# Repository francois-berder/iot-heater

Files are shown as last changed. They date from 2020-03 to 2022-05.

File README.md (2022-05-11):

# Connected heater

The architecture of this solution is as follows: a base station is running and parses incoming SMS. Each heater controller connects to the base station regularly and requests the current heater state.

## Base station

The base station is responsible for parsing incoming SMS that contains commands. It then keeps track of the heater state (off, eco, defrost...) and responds to requests.
It is based on a Raspberry Pi connected to a SIM5320E for cellular connection.

### Hardware

See `docs/base_station_assembly_guide.md` on how to assemble the base station.

### Software

The software is a daemon running on Linux. It communicates with smstools to send/receive SMS from a 3G module.
See `base_station/README.md` for more information.

## Heater controller (or IOT-heater)

Each electric heater can be controlled by sending a SMS to the base station. Heater controllers periodically connect to the base station to retrieve the current heater state.

Electric heaters are controlled by one wire:

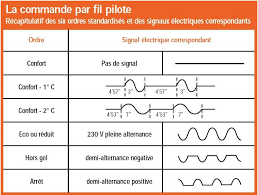
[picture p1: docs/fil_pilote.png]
heater control wire


See [here](https://www.planete-domotique.com/blog/2012/01/05/piloter-un-radiateur-grace-a-son-fil-pilote/) (in french) for more information on this control wire.

### Hardware

Heater controllers are built around a ESP8266 which controls two solid state relays. A small 220VAC to 5VDC module is used to power the ESP8266.
See Kicad files in folder `hardware` for more information.

See `docs/iot_heater_assembly_guide.md` for more information on how to assemble the heater controller.

### Firmware

The firmware is implemented using Arduino libraries for ESP8266.
See `heater_firmware/README.md` for more information.

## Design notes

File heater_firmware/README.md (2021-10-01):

# Heater firmware

This project aims at controlling an electric heater using an ESP8266 and a custom board. This board connects regularly to a base station to obtain the desired heater state (off, defrost, eco...) and controls the heater via a one-wire connection.

## Requirements

[arduino-cli](https://github.com/arduino/arduino-cli) is used to compile and upload binary to the ESP8266 if you are using the Makefile. If you are using the Arduino IDE, you can skip this step.

Run the following command to install arduino-cli:

```sh
curl -fsSL https://raw.githubusercontent.com/arduino/arduino-cli/master/install.sh | BINDIR=/usr/local/bin sh
```

Install ESP8266 board in Arduino IDE:
  1. Open File -> Preferences (or Arduino -> Preferences on MacOS)
  2. Enter `http://arduino.esp8266.com/stable/package_esp8266com_index.json` in the Additional Boards Manager URLs field
  3. Go to Tools -> Board -> Boards Manager and install ESP8266 by ESP8266 Community (version >= 3.0.2)

Arduino library dependencies:

- [ESP8266mDNS](https://github.com/esp8266/Arduino/tree/master/libraries/ESP8266mDNS)
- [ESPAsyncTCP](https://github.com/me-no-dev/ESPAsyncTCP)
- [ESPAsyncWebServer](https://github.com/me-no-dev/ESPAsyncWebServer)
- [ESP8266TrueRandom](https://github.com/marvinroger/ESP8266TrueRandom)
- [NTPClient](https://github.com/arduino-libraries/NTPClient)
- [Uptime-Library](https://github.com/YiannisBourkelis/Uptime-Library)

## Build & Flash instructions

You can either use the Arduino IDE to compile and flash the board, or use the Makefile (requires `arduino-cli`) and run these commands:

```sh
make
make upload
```

## Serial port

The firmware opens a serial connection (115200 8N1) over USB which is currently used only for debug. Run this command to compile/upload and get serial output from the board:

```sh
make term
```

## LED

| Status | LED |
| --- | --- |
| Not commissioned | LED ON |
| Not commissioned but someone on WiFi | LED flash every 100ms |
| Not connected to WiFi | LED flash every 500ms |
| Not connected to base station | LED flash every 3 seconds |
| All OK | LED ON only if reset button is pressed |

## Reset button

If the device is in commissioned mode, pressing the reset button for 10 seconds will reset
the device and clear its configuration. The device comes up in uncommissioned mode.

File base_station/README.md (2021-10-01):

# Base station

## Software

### Build instructions

The program depends on [libmicrohttpd](https://www.gnu.org/software/libmicrohttpd/).
On Ubuntu, run `sudo apt install libmicrohttpd-dev` to install it.

Type `make` or `BUILDTYPE=debug make` to build `base_station` program.

### Raspberry Pi setup

Do not plug anything to the Raspberry Pi apart from the microUSB to power the device. Follow these steps:

1. Flash latest Raspbian on a microSD card
2. Create an empty file named `ssh` in `/boot`
3. Add `wpa_supplicant.conf` in /boot with the following content:

```
country=FR
ctrl_interface=DIR=/var/run/wpa_supplicant GROUP=netdev
update_config=1

network={
  ssid="NETWORK-NAME"
  psk="NETWORK-PASSWORD"
}
```

4. Disable bluetooth by adding `dtoverlay=disable-bt` in `/boot/config.txt`
5. Build installer by running `base_station_installer/build.sh` and transfer this file to the microSD card in `/home/pi`
6. Boot Pi using micro sdcard
7. Login over SSH
8. Change password by running `passwd`
9. Run installer on Raspberry Pi
10. Shutdown Raspberry pi by running `sudo shutdown now`
11. Power up device

## SMS commands

| SMS | Description |
| --- | --- |
| HELP | Reply with basic commands |
| PING | Reply with `PONG` |
| VERSION | Reply with base station software version |
| ALL OFF | Set heater state to OFF |
| ALL DEFROST | Set heater state to DEFROST |
| ALL ECO | Set heater state to ECO |
| ALL COMFORT | Set heater state to COMFORT |
| ALL ON | Set heater state to COMFORT |
| HEATER <name> OFF | Set heater <name> state to OFF |
| HEATER <name> DEFROST | Set heater <name> state to DEFROST |
| HEATER <name> ECO | Set heater <name> state to ECO |
| HEATER <name> COMFORT | Set heater <name> state to COMFORT |
| HEATER <name> ON | Set heater <name> state to COMFORT |
| GET DEFAULT | Reply with current default heater state |
| GET HEATER <name> | Reply with current heater state |
| GET IP | Reply with public IP address |
| LOCK | Only phones whitelisted can send SMS |
| UNLOCK <pin> | All phones can send SMS (default PIN: 1234) |
| ADD PHONE <number> | Add phone number to whitelist |
| REMOVE PHONE <number> | Remove phone number from whitelist |
| DEBUG FILESTATE | Send content of `/var/lib/base_station.state` |
| DEBUG STATE | Send default state and all heater state |
| DEBUG REBOOT | Reboot Raspberry Pi |
| DEBUG WIFI | Get Wifi connection information |
| DEBUG LOG | Send `basestation.service` system logs |
| DEBUG UPTIME | Send Raspberry Pi uptime |
| SET EMERGENCY PHONE <number> | Set emergency phone number |
| REMOVE EMERGENCY PHONE | Remove emergency phone |

### Phone whitelist

By default, all text messages are parsed by the base station software and commands are executed regardless. This implies that anyone that knows the phone number of your base station can control your heating at home. To counter this threat, specific phones can be whitelisted and any text messages sent from a phone not belonging in the whitelist are discarded.

To use this feature,

1. Add your phone number to the whitelist: `ADD PHONE <your-phone-number>`
2. Send this command to enable this feature: `LOCK`

Any phone can send the `UNLOCK` command (useful if you whitelisted the wrong phone number !).

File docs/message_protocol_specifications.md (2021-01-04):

# Message protocol specifications

The base station communicates with heater controllers using a simple protocol.
The protocol consists of fixed size messages (64 bytes). Each message first starts by a header (16 bytes in size) leaving only 48 bytes for message-specific data. All unused bytes must be set to 0xFF.

## Message header

### Message header layout

| Parameter | Size (bytes) |
| --- | ---: |
| Protocol version | 1 |
| Type | 1 |
| MAC address | 6 |
| Counter | 8 |

For now, the protocol version is 1.

The counter is present to allow the base station to detect if a heater controller rebooted. It should be initialized randomly at boot and incremented whenever a message is sent.

### Message types

| Type | Value |
| --- | ---: |
| `REQ_HEATER_STATE` | 1 |
| `HEATER_STATE_REPLY` | 2 |

## `REQ_HEATER_STATE` message

This message may contain a NULL-terminated string that represents the name of the heater controller, making it possible for the base station to send a specific state to each heater.

## `HEATER_STATE_REPLY` message

This message contains only one parameter of size one byte that indicates the heater state. It can take the following values:

| Heater state | Value |
| --- | ----: |
| OFF | 0 |
| DEFROST | 1 |
| ECO | 2 |
| COMFORT/ON | 3 |

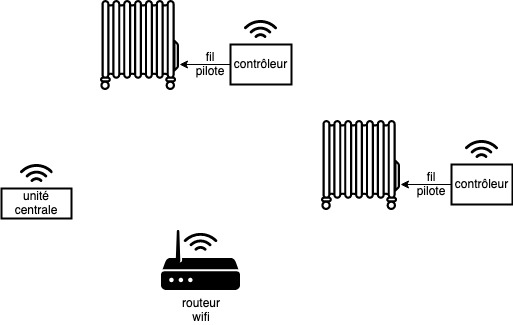
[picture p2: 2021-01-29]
docs/user_guide/connected_heater_overview.jpg

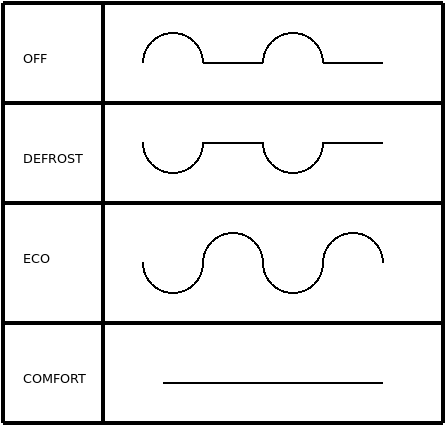
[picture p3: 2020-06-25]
docs/heater_control_wire.png

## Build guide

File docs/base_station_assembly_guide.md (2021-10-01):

# Assembly unit guide for base station

This document is a step by step guide on how to assemble and test base station
device.

## Components required

- Raspberry Pi Zero W
- SIM5320E module
- one micro SD card
- a micro USB to USB-A adapter
- a short micro USB cable
- one 2200uF capacitor (capacitance needs >= 1000uF)
- 2 small wires
- one ABS box

## Assembly

1. Follow the `Raspberry Pi setup` in `base_station/README.md` on how to setup the software on the Raspberry Pi
2. Solder the capacitor on pins 2 and 6 of the Raspberry Pi 40-pin header.
3. Solder one wire from pin 2 of the Raspberry Pi to 5V pin on the SIM5320E
4. Solder one wire from pin 6 of the Raspberry Pi to GND pin on the SIM5320E

The SIM5320E module requires a 4V power supply capable of handling 2A bursts. On the SIM5320E module, a diode lowers the input voltage from 5V to around 4V. Hence, both the Raspberry Pi and the SIM5320E must be powered with a 5V power supply. However, we cannot provide power to the 3G module from the USB connector of the Pi. That is why we need to solder two wires from the Raspberry Pi to the SIM5320E. The large capacitor is there to ensure that the SIM5320E and the Raspberry Pi will not brown when the SIM5320E draws lots of current.

5. Disable SIM card PIN (Can be done on any phone)
6. Insert SIM card in SIM5320E slot
7. Connect the raspberry Pi and SIM5230E with a micro-USB to micro-USB cable.

## Power on

1. Connect to the Raspberry Pi via ssh using public/private keys printed while building the installer.
2. Check that SIM5320E is connected by looking at the content of `/dev`. You should see several `/dev/USB<X>` entries.
3. Check that the basestation service is running: `sudo service basestation status`

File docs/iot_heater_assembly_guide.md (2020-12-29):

# Assembly unit guide for IOT-heater

This document is a step by step guide on how to assemble and test a IOT-heater
device.

## Step 1: Soldering components

Solder the following components on the PCB:

- D1 (5mm green LED)
- D3 (1N40005)
- D4 (1N40005)
- SW1 (push button)
- C1 (0.1uF)
- R1 (1k resistor)
- R2 (1k resistor)
- R4 (1k resistor)
- R7 (1k resistor)
- U2 (CPC1540)
- U3 (CPC1540)
- U1 (2x 15pin header)
- 220VAC to 5VDC converter

Pull-down/Pull-up resistors truth table:

| |  R5  |  R6  |  R8  |  R9  |
| --- | ---- | ---- | ---- | ---- |
| OFF |  fit | | |  fit |
| CONFORT | |  fit | |  fit |
| ECO |  fit | |  fit | |
| DEFROST | |  fit |  fit | |

## Step 2: Power converter test

Do **not** plug a ESP8266

1. Power unit from 220VAC
2. Check that LED from power converter is ON
3. With a multimeter, check power converter output is in range 4.8-5.2V

If successful, solder 5V & GND wires (red wire and black wire)

## Step 3: ESP8266 power test

Plug a ESP8266 device in the unit.

1. Plug a ESP8266
2. Power unit from 220VAC
3. Check LED on ESP8266 is solid ON

## Step 4: ESP8266 programming

1. Connect USB cable from PC to ESP8266
2. Download latest release on https://github.com/francois-berder/iot-heater
3. Run `arduino-cli upload -b esp8266:esp8266:nodemcuv2 -p <serial-port> -i <firmware-file>`

## Step 5: Uncommissioned mode test

1. Power unit from 220VAC
2. Check green LED is solid ON
3. Check WiFi network is present
4. Connect to WiFi network
5. Go to http://192.168.0.1/ and check if a webpage can be seen

## Step 6: commissioned mode test

1. Power unit from 220VAC
2. Go to http://192.168.0.1/ and enter WiFi credentials to commission device
3. Check green LED is off
4. Press for once second the reset button and check that green LED is on
5. Power down base station and check green LED flash every 3 seconds
6. Power down WiFi and check green LED flash every 500ms

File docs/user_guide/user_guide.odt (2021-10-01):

Chauffage connecté

guide d’utilisation

2021-10-01

Version 1

# Description

Le chauffage connecté fonctionne grâce à deux types d’éléments : une unité centrale et les contrôleurs de radiateur. Ces appareils communiquent entre eux grâce au réseau WiFi existant.


Figure 1: Vue d'ensemble de la solution de chauffage connecté

## Unité centrale

L’unité centrale communique avec un modem 3G, pour recevoir et envoyer des SMS, et répond aux requêtes des contrôleurs de radiateur. L’unité centrale est connecté au réseau WiFi de la maison. Il se compose de deux modules : un Raspberry Pi Zero W qui exécute le logiciel de chauffage connecté ainsi qu’un modem 3G relié par USB au Raspberry Pi.

L’unité centrale n’initie jamais une connexion à un contrôleur de radiateur. Il attend les requêtes des contrôleurs et y répond lorsqu’il en reçoit une. Cela a plusieurs conséquences importantes. Il n’est pas possible de connaître à tout moment l’état d’un radiateur. On ne peut que connaître l’état dans lequel le radiateur devrait se trouver. Cependant, cette architecture permet de diminuer la consommation d’énergie des contrôleurs car ils peuvent rester en veille entre deux requêtes.

## Contrôleur radiateur

Les radiateurs électriques sont contrôlés par un fil pilote qui prend la place du fil terre. Ainsi, le contrôleur de radiateur contrôle l’état d’un radiateur via le fil pilote[3].

Les fils phase et neutre alimentent le contrôleur et le radiateur. Un bouton reset est présent. On peut l’appuyer en insérant une pointe de stylo. Il permet de réinitialiser le contrôleur. Enfin, une LED verte est présente pour afficher le statut du contrôleur.

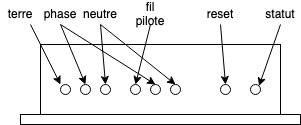
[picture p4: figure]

Figure 2: Vue de côté d'un contrôleur de radiateur

LED | Statut
LED allumée | Le contrôleur n’est pas initialisé
LED clignote toutes les 100 millisecondes | Le contrôleur n’est pas initialisé mais un appareil a rejoint le réseau WiFi du contrôleur
LED clignote toutes les 500 millisecondes | Le contrôleur est initialisé mais n’est pas connecté au WiFi de la maison
LED clignote toutes les 3 secondes | Le contrôleur est initialisé mais n’arrive pas à se connecter à l’unité centrale
LED on si le bouton reset est appuyé, sinon la LED reste éteinte | Le contrôleur est initialisé et fonctionne correctement.

# Installation

## Unité centrale

Avant de mettre en route l’unité centrale, il est vivement recommandé de configurer la box internet pour lui réserver une adresse IP.

Procédure d’installation de l’unité centrale :

1. Ouvrez le boîtier de l’unité centrale et insérez une carte SIM. Assurez-vous que la carte SIM est déverrouillée, c’est-à-dire qu’il n’y a pas besoin d’entrer un code PIN pour la faire fonctionner.
2. Assurez vous que le modem 3G est connecté au Raspberry Pi par un mini câble USB.
3. Connectez l’antenne 3G
4. Pour alimenter l’unité centrale, utilisez une alimentation 5V 2.5A. Il est recommandé d’utiliser une alimentation 5V 12W pour Raspberry Pi. Faîtes attention aux caractéristiques de votre alimentation car il n’existe aucune protection contre une tension trop élevée dans l’unité centrale.
5. Refermez le boîtier.

Lorsque l’appareil est sous tension, des LED vertes et rouge sont allumées (non visible si le boîtier est fermé).

Vous pouvez placer votre unité centrale où vous voulez tant que les connexions WiFi et 3G sont stables.

## Contrôleur radiateur

Avant d’initialiser un contrôleur, il est recommandé de configurer la box internet pour réserver une adresse IP à celui-ci.

Procédure d’installation d’un contrôleur :

1. Assurez vous que le radiateur est hors tension
2. Connectez les fils phase/neutre/terre au contrôleur
3. Connectez les fils phase/neutre/pilote au radiateur
4. Allumez le radiateur
5. Appuyez sur le bouton reset jusqu’à ce que la LED reste allumée
6. Connectez vous au réseau WiFi du contrôleur (le nom et mot de passe de ce réseau WiFi sont marqués sur le côté du boîtier)
7. Ouvrez un navigateur internet et allez à l’adresse http://www.heater.local ou http://192.168.1.1
8. Remplissez le formulaire et appuyez sur le bouton Register. Le réseau WiFi du contrôleur est supprimé et l’appareil tente de se connecter au réseau WiFi grâce aux informations fournis par le formulaire. Si cette connexion réussit, l’appareil est initialisé et se connecte régulièrement à l’unité centrale.

Le nom du radiateur doit être composé de lettres minuscule, majuscule ou de chiffres. Il ne doit pas y avoir d’espaces ou d’autres symboles dans le nom du radiateur.

Si vous initialisez plusieurs contrôleurs, évitez de leur donner le même nom. De plus, deux contrôleurs nommés Salon et SALON sont considérés comme ayant le même nom.

Attention ! Ne connectez pas plusieurs radiateurs à un seul contrôleur, les composants ne sont pas spécifié pour des courants trop élevé (maximum : 13A).

# Utilisation

Les radiateurs se pilotent uniquement par SMS via l'unité centrale. Il n'existe aucun autre moyen de changer l'état d'un radiateur.

Toutes les commandes dans ce document sont écrites en lettre majuscule, cependant l'unité centrale ne fait aucune différence si une lettre est en majuscule ou en minuscule, y compris pour les noms des radiateurs.

Les radiateurs sont toujours dans l'un des états suivants: OFF, DEFROST, ECO ou ON. Un réglage par défaut s'applique à tous les radiateurs sauf si un réglage particulier est associé à un radiateur.

## Commander tous les radiateurs

Il existe quatre commandes pour commander tous les radiateurs dans un mode :

Commande | Description
ALL OFF | Tous les radiateurs sont éteints
ALL DEFROST | Tous les radiateurs sont en mode dégel
ALL ECO | Tous les radiateurs sont en mode eco
ALL ON | Tous les radiateurs sont allumés

Si l'unité centrale a reçu et traité correctement le SMS, une confirmation est envoyée par SMS (cela peut prendre quelques minutes pour recevoir la confirmation).

## Commander un radiateur

Il existe quatre commandes pour commander un radiateur dans un mode :

Commande | Description
HEATER <name> OFF | Eteint le radiateur <name>
HEATER <name> DEFROST | Place le radiateur <name> en mode dégel
HEATER <name> ECO | Place le radiateur <name> en mode eco
HEATER <name> ON | Allume le radiateur <name>

Le paramètre <name> doit être remplacé par le nom du radiateur. Par exemple, HEATER SALON ON ou HEATER CHAMBRE1 ECO. L'unité centrale renvoie un SMS pour confirmer la commande.

Si vous avez initialisé deux contrôleurs avec le même nom, ils seront toujours dans le même état. Ainsi, une seule commande peut contrôler un groupe de radiateurs.

## Obtenir l’état du chauffage

Il existe deux commandes pour obtenir l’état des radiateurs :

Commande | Description
GET DEFAULT | Renvoie l’état par défaut
GET HEATER <name> | Renvoie l’état d’un radiateur

Attention la commande GET HEATER renvoie l’état dans lequel le radiateur devrait se trouver. L’unité centrale n’est pas capable de déterminer l’état réel d’un radiateur.

## Autoriser l’accès uniquement aux numéros autorisés

Par défaut, l’unité centrale accepte les commandes envoyées par n’importe quel téléphone français. Afin de s’assurer qu’uniquement certains numéro de téléphone soient acceptés, il convient de les ajouter à une liste blanche, puis de verrouiller l’unité centrale.

Commande | Description
LOCK | Verrouille l’unité centrale
UNLOCK <pin> | Déverrouille l’unité centrale
ADD PHONE <number> | Ajoute un numéro de téléphone à la liste blanche
REMOVE PHONE <number> | Retire un numéro de téléphone de la liste blanche

Par défaut le code PIN est 1234. Il ne peut pas être modifié une fois le logiciel installé sur l’unité centrale.

Le format du paramètre <number> est le suivant : le numéro +33 (0) 1 23 45 67 89 doit être écrit 33123456789. Ainsi, pour ajouter ce numéro à la liste blanche, envoyez la commande suivante : ADD PHONE 33123456789.

## Alertes

Des alertes sont envoyées par l'unité centrale dans les cas suivants :

- l'unité centrale vient de démarrer
- perte et rétablissement de la connexion WiFi
- un contrôleur a redémarré

Un numéro de téléphone doit être spécifié. Les alertes sont envoyées uniquement à ce numéro.

Commande | Description
SET EMERGENCY PHONE <number>
REMOVE EMERGENCY PHONE | Supprime le numéro d’urgence

Le format du paramètre <number> est le même que pour la commande ADD PHONE <number>. Ainsi, pour ajouter le numéro +33 (0) 7 12 23 34 45, envoyez la commande SET EMERGENCY PHONE 33712233445.

# Diagnostic

### J’envoie des SMS pour commander mes radiateurs mais je ne reçois pas de confirmation. Que faire ?

Dans un premier temps, envoyez la commande PING. L'unité centrale doit répondre par PONG.

Si vous êtes sur place, connectez-vous au réseau WiFi et allez à l'adresse http://basestation pour connaître l'état du modem 3G. Si vous n'arrivez pas à vous connecter à ce site web, ouvrez le boîtier de l'unité centrale. Si vous ne voyez pas de LED verte allumée alors que l'unité centrale est sous tension, alors le Raspberry Pi Zero W ou la carte microSD est défectueuse.

Si vous n’êtes pas sur place, il n’est malheureusement pas possible de déterminer l’origine de la panne.

Causes

- la carte microSD est défectueuse (cela peut arriver après une coupure de courant)
- le modem 3G n’est pas connecté au réseau

Conséquences

L'unité centrale vérifie régulièrement l'état du modem 3G afin de s'assurer que les radiateurs peuvent toujours être commandés. Si le modem 3G ne fonctionne pas, il ordonne à tous les radiateurs de se mettre en mode dégel.

Si l'unité centrale ne fonctionne pas, les radiateurs basculent en mode dégel au bout de 15 minutes.

### Un de mes radiateurs est toujours en mode dégel alors que le reste de mon installation semble fonctionner.

Regardez la LED du contrôleur. Si cette LED clignote tous les 500ms, alors ce contrôleur n'arrive pas à se connecter au réseau WiFi. Si cette LED clignote tous les 3 secondes, alors ce contrôleur n'arrive pas à se connecter à l'unité centrale. Il convient alors de reconfigurer le contrôleur et d'y indiquer l'adresse IP de l'unité centrale.

Causes

- Le signa WiFi est trop faible à l’emplacement du contrôleur
- La configuration du contrôleur est incorrecte ou non à jour et essaie de se connecter à un réseau inexistant ou avec un mot de passe incorrect
- Le contrôleur n’arrive pas à se connecter à l’unité centrale

Conséquences

Ce radiateur restera en mode dégel.

### J'ai reçu une alerte car l'unité centrale a redémarré

Causes

- Une coupure de courant a eu lieu.

Conséquences

Aucune. L'alerte peut être ignorée.

### J'ai reçu une alerte à propos d'une perte de connexion WiFi

Causes

- Le routeur WiFi ne fonctionne plus.
- L'unité centrale est trop loin du routeur WiFi et sa connexion WiFi est instable.

Conséquences

Il n'est plus possible de contrôler les radiateurs. Étant donné que les radiateurs ne peuvent plus se connecter à l'unité centrale, les radiateurs basculent automatiquement en mode dégel au bout de 15 minutes.

### J'ai reçu une alerte car un contrôleur n'a pas donné signe de vie

Causes

- Le contrôleur de ce radiateur est trop loin du routeur WiFi et ne peut communiquer avec celui-ci.
- Le contrôleur est défectueux.

Conséquences

Le radiateur est configuré en mode dégel et il n'est pas possible de changer la configuration de ce radiateur.

### Comment savoir si un contrôleur fonctionne alors que sa LED semble éteinte ?

Appuyez sur le bouton reset pendant 1 à 3 secondes (n'appuyez pas plus longtemps sinon vous risquez de réinitialiser le contrôleur) la LED d'état doit s'allumer.

Si vous connaissez le nom du contrôleur (entré lors de la configuration de ce dernier) ou son adresse IP, essayez d'accéder la page http://<nom-contrôleur> ou http://<address-IP>.

### J’ai changé de mot de passe du WiFi, que dois-je faire ?

Tous les contrôleurs doivent être réinitialisés en appliquant la procédure décrite à l’installation du contrôleur.

L’unité centrale doit également être modifié :

1. Éteignez l’unité centrale
2. Retirez la carte microSD et insérez-la dans un ordinateur
3. Créez le fichier wpa_supplicant.conf dans la partition boot avec ce contenu :

ctrl_interface=DIR=/var/run/wpa_supplicant GROUP=netdev

update_config=1

country=FR

network={

ssid="<nom reseau wifi>"

psk="<mot de passe>"

}

4. Insérez la carte microSD dans le Raspberry Pi et rallumez l’unité centrale

### Le chauffage ne semble pas fonctionner. Comment obtenir des informations sur l’origine de la panne ?

Si l’unité centrale répond aux SMS, envoyez ces commandes : DEBUG LOG, DEBUG WIFI, DEBUG UPTIME, DEBUG FILESTATE, DEBUG STATE.

Si vous êtes sur place, en plus d’envoyer les commandes par SMS, essayez de vous connecter au site web de l’unité centrale à l’adresse http://basestati (http://basestation/)on.local (http://basestation/) ou http://<adresse-IP-unite-centrale>. Des informations sur l’état du modem 3G et des radiateurs sont disponibles.

# Annexes

Table 1: Description des commandes par SMS

Command | Description
HELP | Reply with basic commands
PING | Reply with PONG
VERSION | Reply with basestation software version
ALL OFF | Set default heater state to OFF
ALL ECO | Set default heater state to ECO
ALL DEFROST | Set default heater state to DEFROST
ALL ON | Set default heater state to ON
HEATER <name> OFF | Set heater state to OFF
HEATER <name> ECO | Set heater state to ECO
HEATER <name> DEFROST | Set heater state to DEFROST
HEATER <name> ON | Set heater state to ON
GET DEFAULT | Reply with default heater state
GET HEATER <name> | Reply with heater state
GET IP | Reply with public IP address
LOCK | Lock software (only whitelisted phones can send commands)
UNLOCK <pin> | Unlock software
ADD PHONE <number> | Add phone to whitelist
REMOVE PHONE <number> | Remove phone from whitelist
SET EMERGENCY PHONE <number> | Set emergency phone
REMOVE EMERGENCY PHONE | Remove emergency phone
DEBUG FILESTATE | Send configuration file content
DEBUG STATE | Send default state all heater state
DEBUG REBOOT | Reboot Raspberry Pi
DEBUG WIFI | Get WiFi connection information
DEBUG LOG | Send basestation service logs
DEBUG UPTIME | Send Raspberry Pi uptime


Figure 3: Commande par fil pilote

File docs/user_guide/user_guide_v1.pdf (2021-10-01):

# Chauffage connecté

# guide d’utilisation

2021-10-01
Version 1

# Description

Le chauffage connecté fonctionne grâce à deux types d’éléments : une unité centrale et les contrôleurs de radiateur. Ces appareils communiquent entre eux grâce au réseau WiFi existant.

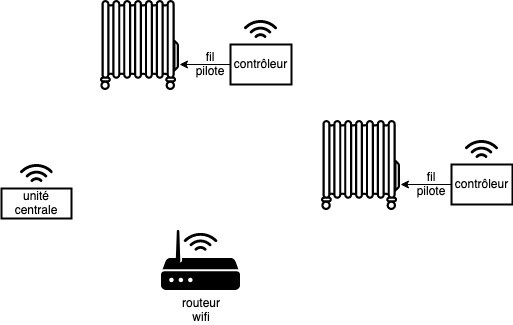
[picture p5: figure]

## Unité centrale

L’unité centrale communique avec un modem 3G, pour recevoir et envoyer des SMS, et répond aux requêtes des contrôleurs de radiateur. L’unité centrale est connecté au réseau WiFi de la maison. Il se compose de deux modules : un Raspberry Pi Zero W qui exécute le logiciel de chauffage connecté ainsi qu’un modem 3G relié par USB au Raspberry Pi.

L’unité centrale n’initie jamais une connexion à un contrôleur de radiateur. Il attend les requêtes des contrôleurs et y répond lorsqu’il en reçoit une. Cela a plusieurs conséquences importantes. Il n’est pas possible de connaître à tout moment l’état d’un

Figure 1: Vue d'ensemble de la solution de chauffage connecté radiateur. On ne peut que connaître l’état dans lequel le radiateur devrait se trouver. Cependant, cette architecture permet de diminuer la consommation d’énergie des contrôleurs car ils peuvent rester en veille entre deux requêtes.

## Contrôleur radiateur

Les radiateurs électriques sont contrôlés par un fil pilote qui prend la place du fil terre. Ainsi, le contrôleur de radiateur contrôle l’état d’un radiateur via le fil pilote[3].
Les fils phase et neutre alimentent le contrôleur et le radiateur. Un bouton reset est présent. On peut l’appuyer en insérant une pointe de stylo. Il permet de réinitialiser le contrôleur. Enfin, une LED verte est présente pour afficher le statut du contrôleur.

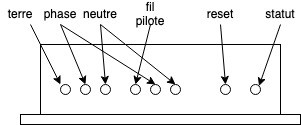
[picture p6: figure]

LED | Statut
LED allumée | Le contrôleur n’est pas initialisé
LED clignote toutes les 100 millisecondes | Le contrôleur n’est pas initialisé mais un appareil a rejoint le réseau WiFi du contrôleur
LED clignote toutes les 500 millisecondes | Le contrôleur est initialisé mais n’est pas connecté au WiFi de la maison
LED clignote toutes les 3 secondes | Le contrôleur est initialisé mais n’arrive pas à se connecter à l’unité centrale
LED on si le bouton reset est appuyé, sinon la LED reste éteinte | Le contrôleur est initialisé et fonctionne correctement.

Figure 2: Vue de côté d'un contrôleur de radiateur

# Installation

## Unité centrale

Avant de mettre en route l’unité centrale, il est vivement recommandé de configurer la box internet pour lui réserver une adresse IP.
Procédure d’installation de l’unité centrale :
1. Ouvrez le boîtier de l’unité centrale et insérez une carte SIM. Assurez-vous que la carte SIM est déverrouillée, c’est-à-dire qu’il n’y a pas besoin d’entrer un code PIN pour la faire fonctionner.
2. Assurez vous que le modem 3G est connecté au Raspberry Pi par un mini câble USB.
3. Connectez l’antenne 3G
4. Pour alimenter l’unité centrale, utilisez une alimentation 5V 2.5A. Il est recommandé d’utiliser une alimentation 5V 12W pour Raspberry Pi. Faîtes attention aux caractéristiques de votre alimentation car il n’existe aucune protection contre une tension trop élevée dans l’unité centrale.
5. Refermez le boîtier.
Lorsque l’appareil est sous tension, des LED vertes et rouge sont allumées (non visible si le boîtier est fermé).
Vous pouvez placer votre unité centrale où vous voulez tant que les connexions WiFi et 3G sont stables.

## Contrôleur radiateur

Avant d’initialiser un contrôleur, il est recommandé de configurer la box internet pour réserver une adresse IP à celui-ci.
Procédure d’installation d’un contrôleur :
1. Assurez vous que le radiateur est hors tension
2. Connectez les fils phase/neutre/terre au contrôleur
3. Connectez les fils phase/neutre/pilote au radiateur
4. Allumez le radiateur
5. Appuyez sur le bouton reset jusqu’à ce que la LED reste allumée
6. Connectez vous au réseau WiFi du contrôleur (le nom et mot de passe de ce réseau WiFi sont marqués sur le côté du boîtier)

7. Ouvrez un navigateur internet et allez à l’adresse http://www.heater.local ou http://192.168.1.1
8. Remplissez le formulaire et appuyez sur le bouton Register. Le réseau WiFi du contrôleur est supprimé et l’appareil tente de se connecter au réseau WiFi grâce aux informations fournis par le formulaire. Si cette connexion réussit, l’appareil est initialisé et se connecte régulièrement à l’unité centrale.
Le nom du radiateur doit être composé de lettres minuscule, majuscule ou de chiffres. Il ne doit pas y avoir d’espaces ou d’autres symboles dans le nom du radiateur. Si vous initialisez plusieurs contrôleurs, évitez de leur donner le même nom. De plus, deux contrôleurs nommés Salon et SALON sont considérés comme ayant le même nom.
Attention ! Ne connectez pas plusieurs radiateurs à un seul contrôleur, les composants ne sont pas spécifié pour des courants trop élevé (maximum : 13A).

# Utilisation

Les radiateurs se pilotent uniquement par SMS via l'unité centrale. Il n'existe aucun autre moyen de changer l'état d'un radiateur.
Toutes les commandes dans ce document sont écrites en lettre majuscule, cependant l'unité centrale ne fait aucune différence si une lettre est en majuscule ou en minuscule, y compris pour les noms des radiateurs.
Les radiateurs sont toujours dans l'un des états suivants: OFF, DEFROST, ECO ou ON. Un réglage par défaut s'applique à tous les radiateurs sauf si un réglage particulier est associé à un radiateur.

## Commander tous les radiateurs

Il existe quatre commandes pour commander tous les radiateurs dans un mode :

Commande | Description
ALL OFF | Tous les radiateurs sont éteints
ALL DEFROST | Tous les radiateurs sont en mode dégel
ALL ECO | Tous les radiateurs sont en mode eco
ALL ON | Tous les radiateurs sont allumés

Si l'unité centrale a reçu et traité correctement le SMS, une confirmation est envoyée par SMS (cela peut prendre quelques minutes pour recevoir la confirmation).

## Commander un radiateur

Il existe quatre commandes pour commander un radiateur dans un mode :

Commande | Description
HEATER <name> OFF | Eteint le radiateur <name>
HEATER <name> DEFROST | Place le radiateur <name> en mode dégel
HEATER <name> ECO | Place le radiateur <name> en mode eco
HEATER <name> ON | Allume le radiateur <name>

Le paramètre <name> doit être remplacé par le nom du radiateur. Par exemple, HEATER SALON ON ou HEATER CHAMBRE1 ECO. L'unité centrale renvoie un SMS pour confirmer la commande.
Si vous avez initialisé deux contrôleurs avec le même nom, ils seront toujours dans le même état. Ainsi, une seule commande peut contrôler un groupe de radiateurs.

## Obtenir l’état du chauffage

Il existe deux commandes pour obtenir l’état des radiateurs :

Commande | Description
GET DEFAULT | Renvoie l’état par défaut
GET HEATER <name> | Renvoie l’état d’un radiateur

Attention la commande GET HEATER renvoie l’état dans lequel le radiateur devrait se trouver. L’unité centrale n’est pas capable de déterminer l’état réel d’un radiateur.

## Autoriser l’accès uniquement aux numéros autorisés

Par défaut, l’unité centrale accepte les commandes envoyées par n’importe quel téléphone français. Afin de s’assurer qu’uniquement certains numéro de téléphone soient acceptés, il convient de les ajouter à une liste blanche, puis de verrouiller l’unité centrale.

Commande | Description
LOCK | Verrouille l’unité centrale
UNLOCK <pin> | Déverrouille l’unité centrale
ADD PHONE <number> | Ajoute un numéro de téléphone à la liste blanche
REMOVE PHONE <number> | Retire un numéro de téléphone de la liste blanche

Par défaut le code PIN est 1234. Il ne peut pas être modifié une fois le logiciel installé sur l’unité centrale.

Le format du paramètre <number> est le suivant : le numéro +33 (0) 1 23 45 67 89 doit être écrit 33123456789. Ainsi, pour ajouter ce numéro à la liste blanche, envoyez la commande suivante : ADD PHONE 33123456789.

## Alertes

Des alertes sont envoyées par l'unité centrale dans les cas suivants :
- l'unité centrale vient de démarrer
- perte et rétablissement de la connexion WiFi
- un contrôleur a redémarré
Un numéro de téléphone doit être spécifié. Les alertes sont envoyées uniquement à ce numéro.
Commande | Description
SET EMERGENCY PHONE <number>
REMOVE EMERGENCY PHONE | Supprime le numéro d’urgence

Le format du paramètre <number> est le même que pour la commande ADD PHONE <number>. Ainsi, pour ajouter le numéro +33 (0) 7 12 23 34 45, envoyez la commande SET EMERGENCY PHONE 33712233445.

# Diagnostic

### J’envoie des SMS pour commander mes radiateurs mais je ne reçois pas de confirmation. Que faire ?

Dans un premier temps, envoyez la commande PING. L'unité centrale doit répondre par PONG.
Si vous êtes sur place, connectez-vous au réseau WiFi et allez à l'adresse http://basestation pour connaître l'état du modem 3G. Si vous n'arrivez pas à vous connecter à ce site web, ouvrez le boîtier de l'unité centrale. Si vous ne voyez pas de LED verte allumée alors que l'unité centrale est sous tension, alors le Raspberry Pi Zero W ou la carte microSD est défectueuse.
Si vous n’êtes pas sur place, il n’est malheureusement pas possible de déterminer l’origine de la panne.

Causes

- la carte microSD est défectueuse (cela peut arriver après une coupure de courant)
- le modem 3G n’est pas connecté au réseau

Conséquences
L'unité centrale vérifie régulièrement l'état du modem 3G afin de s'assurer que les radiateurs peuvent toujours être commandés. Si le modem 3G ne fonctionne pas, il ordonne à tous les radiateurs de se mettre en mode dégel.
Si l'unité centrale ne fonctionne pas, les radiateurs basculent en mode dégel au bout de 15 minutes.

### Un de mes radiateurs est toujours en mode dégel alors que le reste de

mon installation semble fonctionner.

Regardez la LED du contrôleur. Si cette LED clignote tous les 500ms, alors ce contrôleur n'arrive pas à se connecter au réseau WiFi. Si cette LED clignote tous les 3 secondes, alors ce contrôleur n'arrive pas à se connecter à l'unité centrale. Il convient alors de reconfigurer le contrôleur et d'y indiquer l'adresse IP de l'unité centrale.

Causes
- Le signa WiFi est trop faible à l’emplacement du contrôleur
- La configuration du contrôleur est incorrecte ou non à jour et essaie de se connecter à un réseau inexistant ou avec un mot de passe incorrect
- Le contrôleur n’arrive pas à se connecter à l’unité centrale

Conséquences
Ce radiateur restera en mode dégel.

### J'ai reçu une alerte car l'unité centrale a redémarré

Causes
- Une coupure de courant a eu lieu.

Conséquences

Aucune. L'alerte peut être ignorée.

### J'ai reçu une alerte à propos d'une perte de connexion WiFi

Causes
- Le routeur WiFi ne fonctionne plus.
- L'unité centrale est trop loin du routeur WiFi et sa connexion WiFi est instable.

Conséquences
Il n'est plus possible de contrôler les radiateurs. Étant donné que les radiateurs ne peuvent plus se connecter à l'unité centrale, les radiateurs basculent automatiquement en mode dégel au bout de 15 minutes.

### J'ai reçu une alerte car un contrôleur n'a pas donné signe de vie

Causes
- Le contrôleur de ce radiateur est trop loin du routeur WiFi et ne peut communiquer avec celui-ci.
- Le contrôleur est défectueux.

Conséquences
Le radiateur est configuré en mode dégel et il n'est pas possible de changer la configuration de ce radiateur.

### Comment savoir si un contrôleur fonctionne alors que sa LED semble éteinte ?

Appuyez sur le bouton reset pendant 1 à 3 secondes (n'appuyez pas plus longtemps sinon vous risquez de réinitialiser le contrôleur) la LED d'état doit s'allumer. Si vous connaissez le nom du contrôleur (entré lors de la configuration de ce dernier) ou son adresse IP, essayez d'accéder la page http://<nom-contrôleur> ou http://<address-IP>.

### J’ai changé de mot de passe du WiFi, que dois-je faire ?

Tous les contrôleurs doivent être réinitialisés en appliquant la procédure décrite à l’installation du contrôleur.
L’unité centrale doit également être modifié :
1. Éteignez l’unité centrale
2. Retirez la carte microSD et insérez-la dans un ordinateur
3. Créez le fichier wpa_supplicant.conf dans la partition boot avec ce contenu :

ctrl_interface=DIR=/var/run/wpa_supplicant GROUP=netdev
update_config=1
country=FR

network={
ssid="<nom reseau wifi>"
psk="<mot de passe>"
}
4. Insérez la carte microSD dans le Raspberry Pi et rallumez l’unité centrale

### Le chauffage ne semble pas fonctionner. Comment obtenir des informations sur l’origine de la panne ?

Si l’unité centrale répond aux SMS, envoyez ces commandes : DEBUG LOG, DEBUG WIFI, DEBUG UPTIME, DEBUG FILESTATE, DEBUG STATE.
Si vous êtes sur place, en plus d’envoyer les commandes par SMS, essayez de vous connecter au site web de l’unité centrale à l’adresse http://basestati (http://basestation/) on.local (http://basestation/) ou http://<adresse-IP-unite-centrale>. Des informations sur l’état du modem 3G et des radiateurs sont disponibles.

# Annexes

Table 1: Description des commandes par SMS

Command | Description
HELP | Reply with basic commands
PING | Reply with PONG
VERSION | Reply with basestation software version
ALL OFF | Set default heater state to OFF
ALL ECO | Set default heater state to ECO
ALL DEFROST | Set default heater state to DEFROST
ALL ON | Set default heater state to ON
HEATER <name> OFF | Set heater state to OFF
HEATER <name> ECO | Set heater state to ECO
HEATER <name> DEFROST | Set heater state to DEFROST
HEATER <name> ON | Set heater state to ON
GET DEFAULT | Reply with default heater state
GET HEATER <name> | Reply with heater state
GET IP | Reply with public IP address
LOCK | Lock software (only whitelisted phones can send commands)
UNLOCK <pin> | Unlock software
ADD PHONE <number> | Add phone to whitelist
REMOVE PHONE <number> | Remove phone from whitelist
SET EMERGENCY PHONE <number> | Set emergency phone
REMOVE EMERGENCY PHONE | Remove emergency phone
DEBUG FILESTATE | Send configuration file content
DEBUG STATE | Send default state all heater state
DEBUG REBOOT | Reboot Raspberry Pi
DEBUG WIFI | Get WiFi connection information
DEBUG LOG | Send basestation service logs
DEBUG UPTIME | Send Raspberry Pi uptime


Figure 3: Commande par fil pilote

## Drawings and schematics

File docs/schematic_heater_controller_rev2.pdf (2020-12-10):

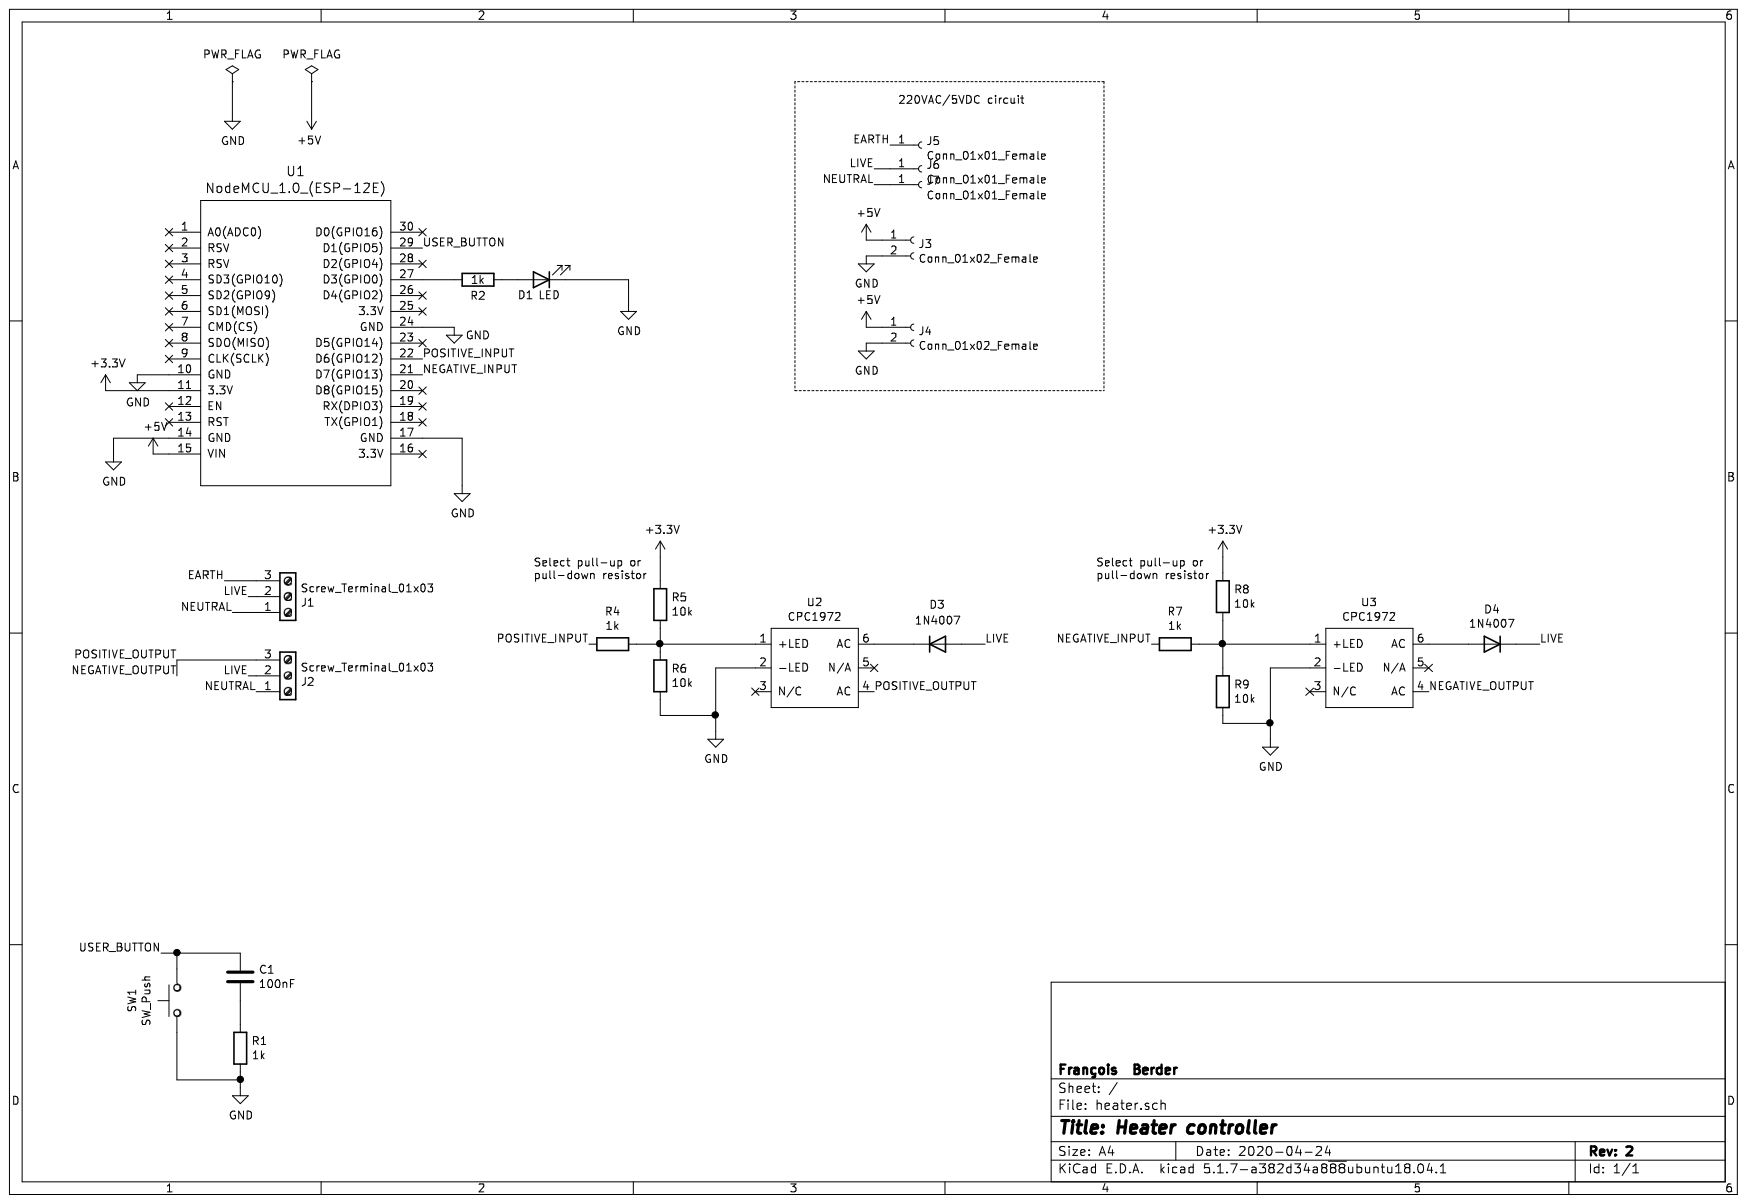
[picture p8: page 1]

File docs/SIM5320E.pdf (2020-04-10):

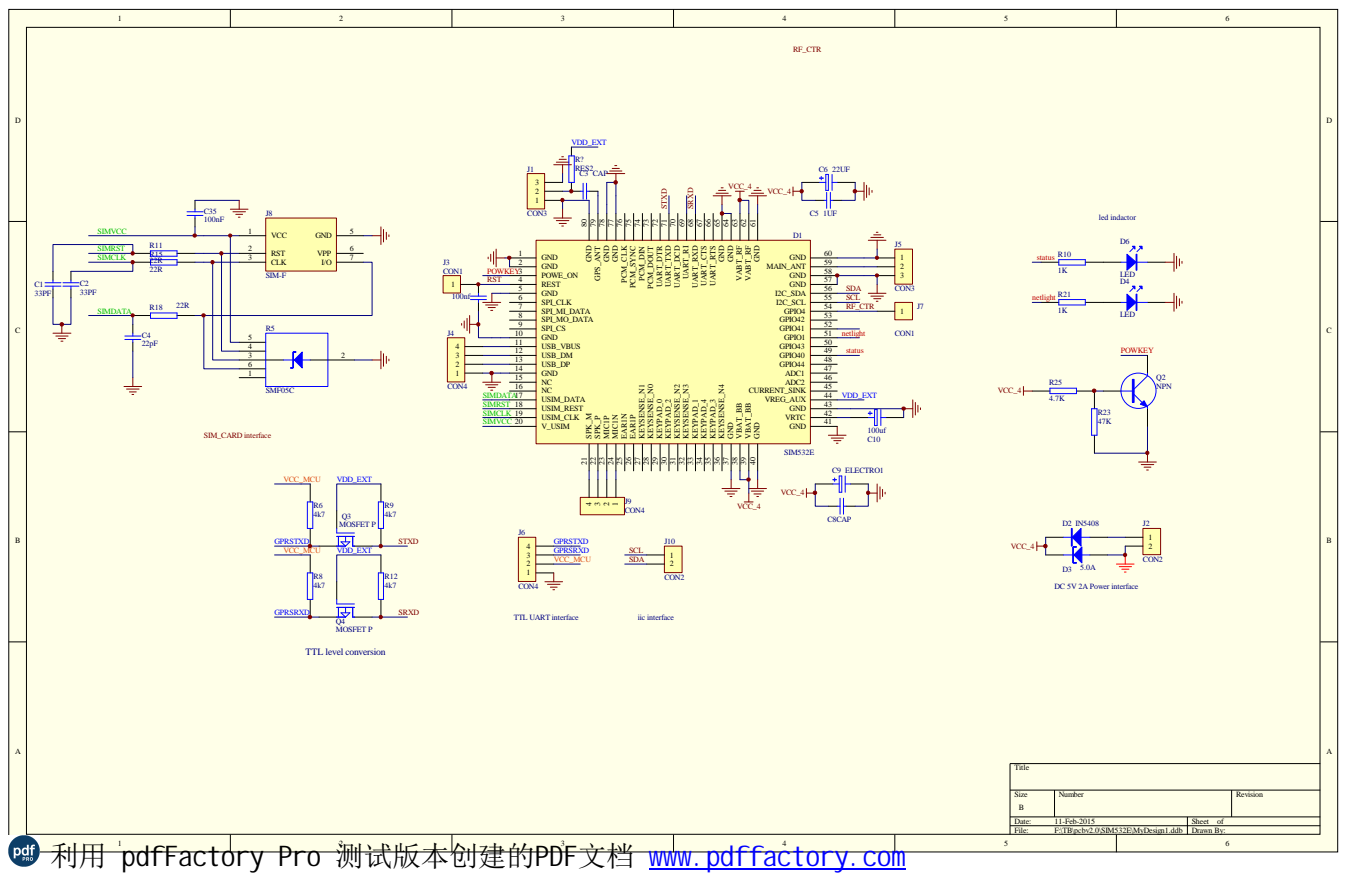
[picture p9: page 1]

利用 pdfFactory Pro 测试版本创建的PDF文档 www.pdffactory.com

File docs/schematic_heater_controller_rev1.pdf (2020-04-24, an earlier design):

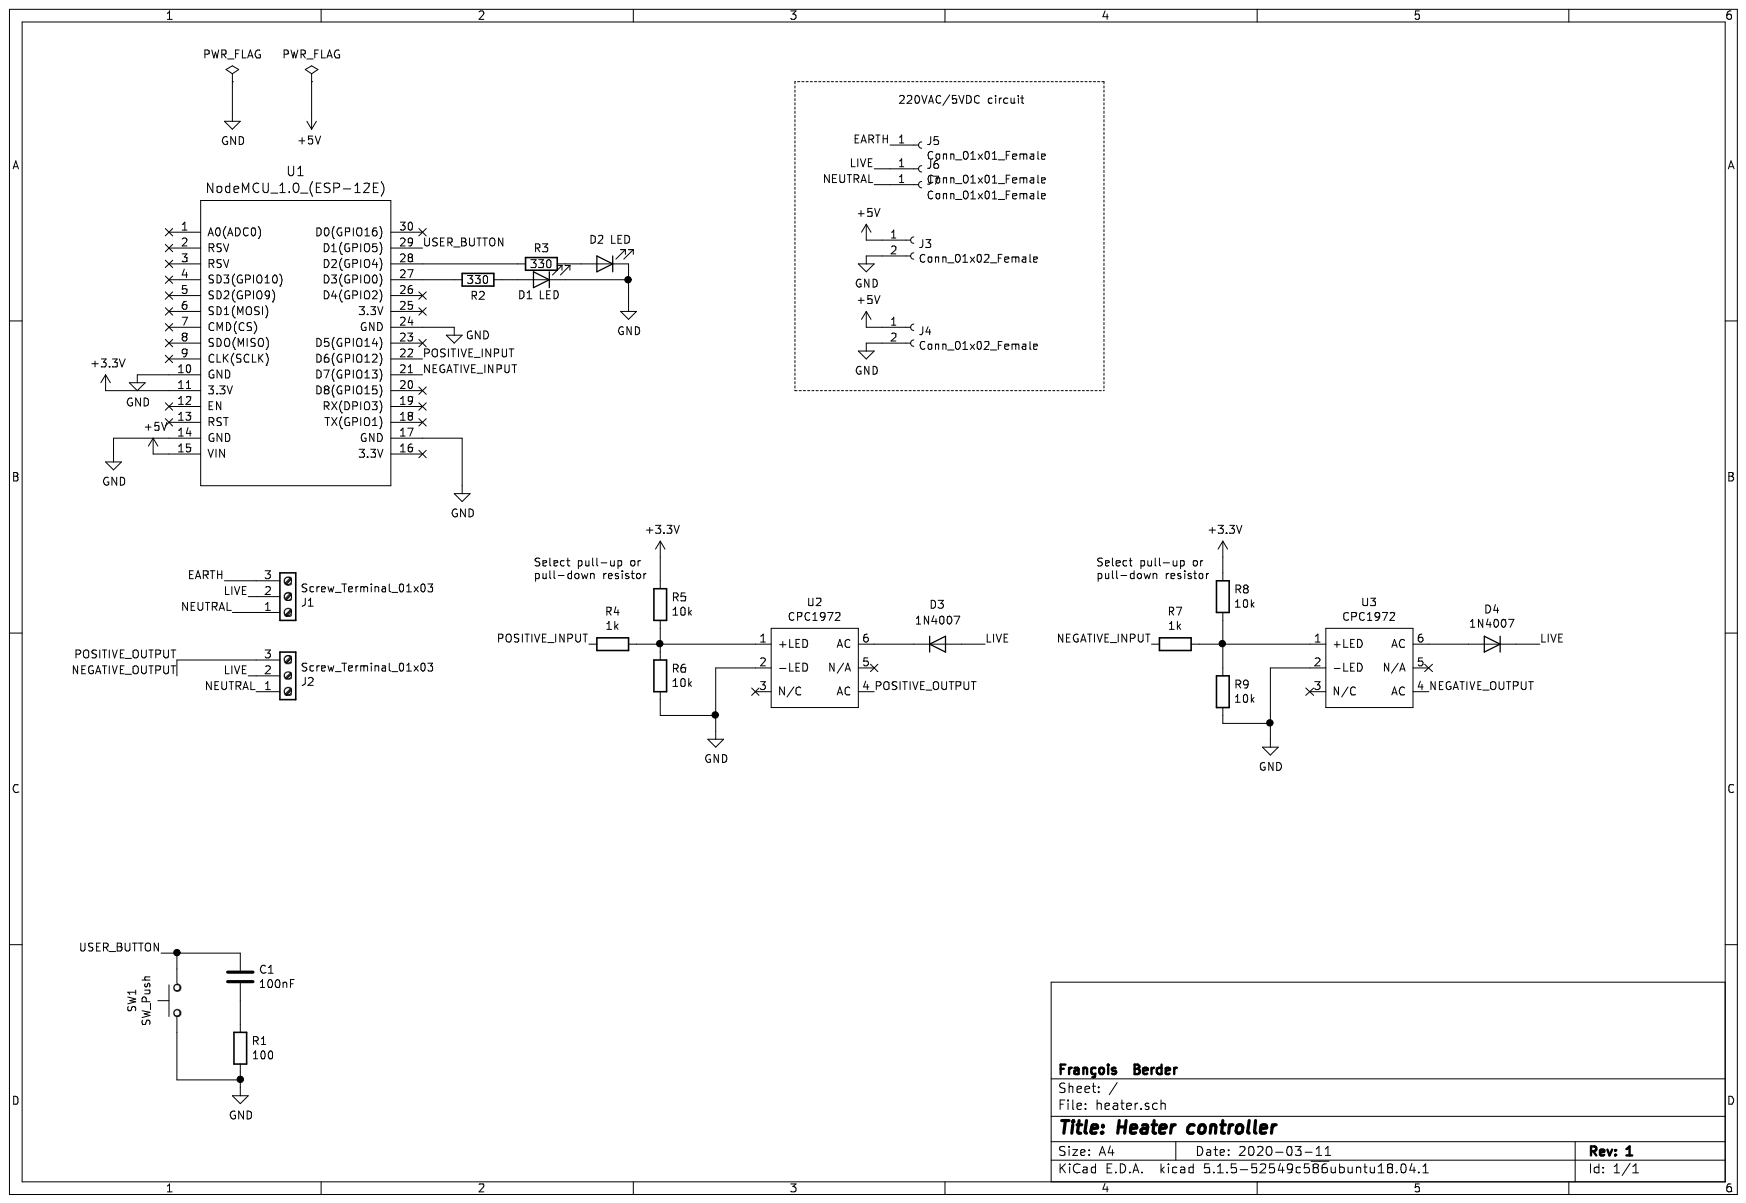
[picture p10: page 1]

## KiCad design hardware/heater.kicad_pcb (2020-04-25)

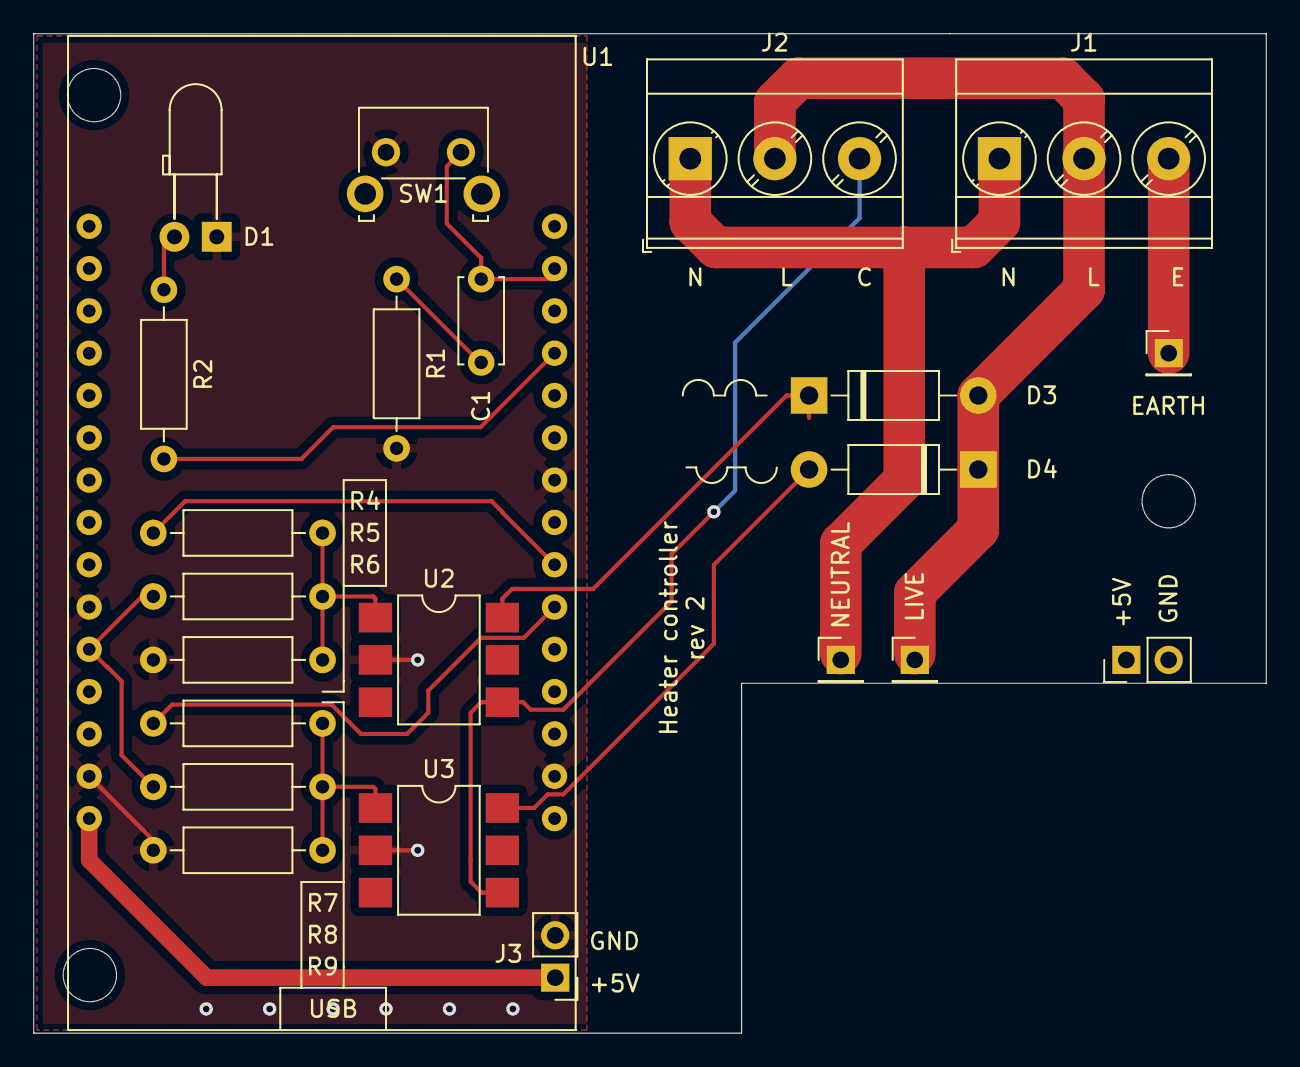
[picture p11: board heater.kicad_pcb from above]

Board: 2 copper layers, 74.0 x 60.0 mm, 23 parts (0 on the bottom side), 17 nets.

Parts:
C1: 100nF; C_Disc_D5.0mm_W2.5mm_P5.00mm
D1: LED; LED_D3.0mm_Horizontal_O3.81mm_Z2.0mm
D3, D4: 1N4007; D_DO-41_SOD81_P10.16mm_Horizontal
J1, J2: Screw_Terminal_01x03; TerminalBlock_Phoenix_MKDS-3-3-5.08_1x03_P5.08mm_Horizontal
J3, J4: Conn_01x02_Female; PinHeader_1x02_P2.54mm_Vertical
J5, J6, J7: Conn_01x01_Female; PinHeader_1x01_P2.54mm_Vertical
R1, R2, R4, R7: 1k; R_Axial_DIN0207_L6.3mm_D2.5mm_P10.16mm_Horizontal
R5, R6, R8, R9: 10k; R_Axial_DIN0207_L6.3mm_D2.5mm_P10.16mm_Horizontal
SW1: SW_Push; SW_Tactile_SKHH_Angled
U1: NodeMCU_1.0_(ESP-12E); NodeMCU
U2, U3: CPC1972; SMDIP-6_W7.62mm

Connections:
+3V3: R5.1, R8.1, U1.11
+5V: J3.1, J4.1, U1.15
/EARTH: J1.3, J5.1
/LIVE: D3.2, D4.1, J1.2, J2.2, J6.1
/NEGATIVE_INPUT: R7.2, U1.21
/NEGATIVE_OUTPUT: J2.3, U2.4, U3.4
/NEUTRAL: J1.1, J2.1, J7.1
/POSITIVE_INPUT: R4.2, U1.22
/USER_BUTTON: C1.1, SW1.2, U1.29
GND: D1.1, J3.2, J4.2, R1.2, R6.2, R9.2, SW1.1, U1.10, U1.14, U1.17, U1.24, U2.2, U3.2
unnamed: C1.2, R1.1
unnamed: D1.2, R2.1
unnamed: D3.1, U2.6
unnamed: D4.2, U3.6
unnamed: R2.2, U1.27
unnamed: R4.1, R5.2, R6.1, U2.1
unnamed: R7.1, R8.2, R9.1, U3.1

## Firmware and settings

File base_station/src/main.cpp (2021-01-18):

#include <functional>
#include <iostream>
#include <sstream>
#include "base_station.hpp"
#include "logger.hpp"
#include "device_server.hpp"
#include "sms_receiver.hpp"
#include "version.hpp"
#include "web_server.hpp"

#define DEFAULT_DEVICE_SERVER_PORT  (32322)

static void print_help(char *program_name)
{
    std::cout << "Usage: " << program_name << " [options]\n"
              << "Options:\n"
              << "    --device-server-port <port>       Set device server port\n"
              << "    --version, -v                     Print version\n"
              << "    --help, -h                        Print help\n"
              << std::flush;
}

static void wait_ms(unsigned int ms)
{
    struct timespec req, rem;
    req.tv_sec = ms / 1000;
    req.tv_nsec = (ms - req.tv_sec * 1000) * 1000 * 1000;
    while (nanosleep(&req, &rem))
        req = rem;
}

int main(int argc, char **argv)
{
    char *program_name = argv[0];
    int device_server_port = DEFAULT_DEVICE_SERVER_PORT;

    argc--;
    argv++;
    while (argc) {
        std::string opt(argv[0]);
        if (opt == "--device-server-port" && argc >= 2) {
            std::string optarg(argv[1]);
            device_server_port = std::stoi(optarg);
            argc--;
            argv++;
        } else if (opt == "--help" || opt == "-h") {
            print_help(program_name);
            return 0;
        } else if (opt == "--version" || opt == "-v") {
            std::cout << get_version_str() << std::endl;
            return 0;
        } else {
            std::cerr << "Invalid option: \"" << opt << '\"' << std::endl;
            print_help(program_name);
            return -1;
        }

        argc--;
        argv++;
    }


    Logger::instance().startLogging(".");
    {
        std::stringstream ss;
        ss << program_name << " (version: " << get_version_str() <<  ") started";
        Logger::info(ss.str());
    }

    BaseStation base_station;
    DeviceServer device_server(device_server_port,
                               std::bind(&BaseStation::handleNewDevice, &base_station, std::placeholders::_1));
    device_server.start();

    SMSReceiver sms_receiver(std::bind(&BaseStation::handleSMSCommand, &base_station, std::placeholders::_1, std::placeholders::_2));
    sms_receiver.start();

    WebServer web_server(&base_station);
    web_server.start();

    while (true) {
        base_station.process();
        wait_ms(50);
    }

    web_server.stop();
    sms_receiver.stop();
    device_server.stop();
    Logger::instance().stopLogging();

    return 0;
}

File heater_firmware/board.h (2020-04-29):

#ifndef BOARD_H
#define BOARD_H

#define BUTTON_PIN      (5)
#define LED1_PIN        (0)

#define POSITIVE_OUTPUT_PIN     (12)
#define NEGATIVE_OUTPUT_PIN     (13)

#endif

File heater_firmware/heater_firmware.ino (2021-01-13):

#include "commissioned.h"
#include "settings.h"
#include "uncommissioned.h"
#include "version.h"

bool commissioned;

void setup()
{
    Serial.begin(115200);

    {
        char buffer[128];
        sprintf(buffer, "\nHeater controller (serial: %08X) ", ESP.getChipId());
        Serial.println(buffer);
    }
    Serial.println("Firmware version: " FW_VERSION);

    commissioned = settings_load();

    if (commissioned) {
        Serial.println("Entering commissioned mode");
        setup_commissioned();
    } else {
        Serial.println("Entering uncommissioned mode");
        setup_uncommissioned();
    }
}

void loop()
{
    if (commissioned)
        loop_commissioned();
    else
        loop_uncommissioned();
}

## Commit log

2019-11-20 Blink LEDs in uncommissioned state
2019-11-20 Ensure that heater uses IP address 192.168.1.1
2019-11-20 Run DNS server in uncommissioned state
    User does not have to guess the IP address of the heater controller.
    They simply have to go to www.heater.local to start commissioning their
    device.
2019-11-20 Setup LEDs and button in commissioned state
2019-11-20 Erase settings if button is pressed for 10 seconds
2020-01-31 home_gateway: Implement basic device server
2020-02-01 home_gateway: Implement basic device manager
2020-02-03 home_gateway: Save device info to CSV file
2020-02-10 home_gateway: Implement verbose levels in sms_sender and commands in device manager
2020-02-11 home_gateway: Rename DeviceManager to HomeGateway
2020-02-16 home_gateway: Fix Device::serialize
2020-03-04 home_gateway: Simplify device protocol
2020-03-06 home_gateway: Refactor HomeGateway::process
    * Implement timer
    * Check for stale devices and connections
2020-03-06 home_gateway: Simplify implementation - remove devices
2020-03-07 home_gateway: handle HEATER SMS commands and broadcast heater state
2020-03-07 home_gateway: Load/save heater state to a file
2020-03-07 home_gateway: Handle GET HEATER SMS
2020-03-07 home_gateway: Save state when heater state gets modified
2020-03-07 home_gateway: Handle invalid value for heater_state key
    Also, changed response to GET HEATER SMS
2020-03-17 heater_firmware: Restart when pressing button for a long time
2020-03-17 heater_firmware: Limit names to 31 characters
2020-03-17 heater_firmware: Connect to Wifi client during registration
2020-03-17 heater_firmware: Reduce settings name size to 32 characters
2020-03-17 heater_firmware: Fix settings_create
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2020-03-18 heater_firmware: Erase settings if button is pressed for a while
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2020-03-18 heater_firmware: Restart device if it could not connect to Wifi network
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2020-03-20 heater_firmware: Blink fast while connecting to WiFi network
2020-03-20 heater_firmware: Fix BUTTON_PIN initialization in commissioned mode
    [commissioned.cpp]
2020-03-20 heater_firmware: Refactor code for connecting to wifi in commissioned mode
2020-03-20 heater_firmware: Fix makefile dependencies
2020-03-20 heater_firmware: Use WiFi events to detect when device is connected
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2020-03-21 heater_firmware: Add missing static qualifier
    [commissioned.cpp]
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2020-03-21 heater_firmware: Do not initialize control pins in uncommissioned mode
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2020-03-26 heater_firmware: Turn off heater during initialization in commissioned state
2020-03-26 heater_firmware: Reserve some bytes in settings for future usage
2020-03-26 heater_firmware: Turn off heater if it cannot connect to base station
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2020-03-30 home_gateway: Fix receiving data from devices
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2020-03-30 heater_firmware: Send alive message immediately after being connected to wifi
2020-03-30 heater_firmware: Use base station hostname instead of hard-coded ip address
2020-03-31 heater_firmware: Print git hash and build time during initialization
2020-03-31 heater_firmware: Fix MDNS
2020-03-31 heater_firmware: Fix base station hostname
    [commissioned.cpp]
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2020-04-02 hardware: Add heater_controller gerber files sent to factory
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2020-04-10 Import heater hardware files
    [heater.sch]
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2020-04-13 heater_firmware: Fix LED pattern while not commissioned
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2020-04-24 heater_firmware: Fix all I/O pinout
    [board.h]
2020-04-24 heater_firmware: Fix LED status once heater is connected to WiFi
    [commissioned.cpp]
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2020-04-25 hardware: Design rev2 heater controller board
    [heater.kicad_pcb, heater.sch]
2020-04-25 heater_firmware: Fix status LED in commissioning mode
    [commissioned.cpp]
2020-04-25 heater_firmware: Add more debug print in commissioning mode
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2020-04-29 base_station: Do not be case-sensitive for SMS commands
2020-04-29 base_station: Fix limiting heater history size to 16 elements
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2020-04-30 fixup! heater_firmware: Decrease power consumption in commissioning mode
    [commissioned.cpp]
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2020-06-25 hardware: Add heater controller rev2 gerber files sent to factory
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2020-07-28 heater_firmware: LED ON only if reset button is pressed
    In commissioned mode, it might be annoying during the night if the
    LED is flashing every minute. So, let's turn on the LED only
    if the reset button is pressed. This way, we have a way to check
    that the device is running.
    Also it saves power.
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2020-12-10 Remove UPS pico hat
    Unfortunately , the UPS pico hat did not work very well and
    was constantly rebooting the Pi. The only way to fix this was to use
    a short USB cable. It would only work with a few 5V USB power
    supply.
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2020-12-10 Add some documentation about heater controller in README
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2020-12-30 base_station: Major refactor & bug fixes
    - Control heater state separately
    - Remove heater history feature
    - Add version number in message between base station
    and heater controllers
    - Remove unnecessary prototype
    - Fix GET IP command
    - Remove log levels in SMSSender
    - Add DEBUG commands
2021-01-04 base_station: Print warning if a device rebooted
2021-01-07 heater_firmware: Implement message protocol v1 + other fixes
    - Add dependencies in README
    - Use NTP to get correct date (useful for logs)
    - Check settings at boot
    - Turn heater in DEFROST mode instead of OFF if it cannot
    reach the base station.
    [commissioned.cpp]
2021-01-10 fixup! base_station: Print warning if a device rebooted
2021-01-10 base_station: Periodically check if we lost comms with devices
2021-01-11 heater_firmware: Various improvements, fixes
    - Flash LED quickly if someone connected to Wifi AP
    - Add a bit of jitter to req state timer
    - Use default NTP server (pool.ntp.org)
    - Increase NTP update interval to 15min
    - Increase heater state request interval to 1min
    - Remove suffix to basestation hostname
    - More serial logs
    - Remove hard-coded values
    [commissioned.cpp]
2021-01-11 heater_firmware: Fix LED state in commissioning mode
    If everything is OK, then the LED should be the invert of
    the push button pin. This pin is tied high by a pull-up
    and pressing the button pulls this pin low.
    [commissioned.cpp]
2021-01-11 base_station: Identify lost devices by name instead of MAC if possible
    Keep a mapping of MAC->name updated whenever we receive a state request.
2021-01-11 heater_firmware: Flash LED a few times before restarting after factory reset
    [commissioned.cpp]
2021-01-11 base_station: Fix printing MAC address in logs
    Add debug log when receiving heater state request.
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2021-01-13 heater_firmware: Build webpage only once in uncommssioned mode
2021-01-13 heater_firmware: Show timestamp of last heater state reply from base station
2021-01-13 heater_firmware: Fix buffer overflow while building webpage
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2021-01-13 heater_firmware: Print error count since boot on webpage
    Refactor building of commissioned webpage
    Increase webpage buffer to 1KB.
    [commissioned.cpp]
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2021-01-13 heater_firmware: Fix resetting values when receiving heater state
    [commissioned.cpp]
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2021-01-14 heater_firmware: Reset device from website
    [commissioned.cpp]
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2021-01-18 base_station: Refactor managing heater state
    Add mutex to protect against data race while building web page.
2021-01-18 base_station: Improve version
    - Print version upon startup
    - Add command line to print software version
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2021-01-18 base_station: Increase DEVICE_LOST_THRESHOLD to 24h
    Also, improve message alert to emergency phone.
2021-01-28 base_station: Send message upon startup
    Inform user about current state of all heaters.
2021-01-28 base_station: Fix non-periodic timers
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2021-02-07 heater_firmware: Fix version header filename
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2021-02-07 heater_firmware: Fix commissioned source file name
    [uncommissioned.cpp]
2021-02-07 heater_firmware: Add missing file dependency in makefile
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2021-02-07 heater_firmware: Add missing library dependencies
2021-02-07 heater_firmware: Mention that arduino-cli is only used in the Makefile
2021-02-07 heater_firmware: Explain how to install esp8266 board on Arduino-IDE
2021-02-07 heater_firmware: Mention Arduino IDE to compile project and flash board
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2021-02-08 heater_firmware: Show last 5 errors on web page
    [commissioned.cpp]
2021-02-08 heater_firmware: Show WiFi RSSI level interpretation on web page
2021-02-11 heater_firmware: Fix sending/receiving messages to base station
    write function does not always send the entire message in one call.
    [commissioned.cpp]
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2021-02-20 base_station: Fix reading message from socket
2021-02-20 heater_firmware: Fix error messages
    [commissioned.cpp]
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2021-02-20 heater_firmware: Fix checking timeout
    [commissioned.cpp]
2021-02-20 base_station: Log sending heater state reply failure/success
2021-02-25 base_station: Fix starting stale timer
    Stale timer was not started so stale connections were never removed.
    Also, remove connection after 10 min idle time
2021-02-26 base_station: Fix warning message if device rebooted
2021-03-01 base_station: Increase threshold to 100 for detecting device reboots
    During testing, it appeared that the base station would fail to receive
    a request from a device several times in a row.
    To lower the amount of false positive, let's increase the threshold from
    3 to 100.
2021-03-01 base_station: Immediately close socket fd if no callback set
2021-10-01 docs: Add more steps to base station assembly guide
2021-10-01 heater_firmware: Fix makefile
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2022-05-09 heater_firmware: Fix printing uptime in non commissioned mode
    [uncommissioned.cpp]
2022-05-09 heater_firmware: Do not use soft AP MAC for SSID/password
    soft AP mac address and ST mac address are slightly
    different and this is causing confusion as labels
    on boxes use ST mac address for SSID/password.
